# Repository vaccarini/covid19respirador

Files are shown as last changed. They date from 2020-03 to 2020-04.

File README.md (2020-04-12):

# COVID19 Respirador
Repositorio de un respirador mecánico basado en recomendaciones médicas.

## Introducción
En progreso. Véase el documento: https://docs.google.com/document/d/1z06rEOX_Jf6soLEfomvGs7rINXRS_1dPuQfoMjTGBHs/edit?usp=sharing

## Motivación
La mayoría de los respiradores open source, no cubren los requerimientos médicos mínimos que se necesitan para tratar a un paciente que necesitan tratamiento para el coronavirus.

El diseño de un respirador que funcione y que permita cubrir la baja disponibilidad de los ventiladores UCI se hace imperante. 

Este proyecto intenta crear un ventilador que funcione para los casos indicados.

## Diagrama
En progreso. Véase el documento: https://docs.google.com/document/d/1z06rEOX_Jf6soLEfomvGs7rINXRS_1dPuQfoMjTGBHs/edit?usp=sharing

## Software
El sistema utilizará un módulo arduino. Se buscan colaboradores para el desarrollo y otros aspectos asociados.

## Contacto
Para integrarse al proyecto por favor contactarse con Martín Vaccarini en martin.vaccarini@gmail.com.

## Colaboración en repositorio
* Abrir un nuevo Issue, Forkear el proyecto o realizar un Pull Request.
* También se necesita ayuda en el documento del proyecto: https://docs.google.com/document/d/1z06rEOX_Jf6soLEfomvGs7rINXRS_1dPuQfoMjTGBHs/edit?usp=sharing

Colaboradores:
* Martín Vaccarini (autor) (@vaccarini)
* Ignacio Tolosa (asesor repositorio) (@itolosa)
* Mateo Roldan (alumno escuela Técnica 5)
* Gaston Calderon (alumno escuela técnica 5)
* Eduardo Hisch fábrica de PCB´s
* Javier Schwindt (donó sensor MAF) 
* Adrian Merlo (interlocutor para recibir donaciones)
* Martin ( impresos 3D)
* Nicolas Dumic (colabora teniendo otro proyecto en caminando)
* Walter van Derdonckt (argentina)
* Jon Ander Oribe (España)
* Guille Clave (argentina)
* Sebastian Padilla (españa)

* (Por completar)

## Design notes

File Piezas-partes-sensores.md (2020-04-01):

# Piezas, Partes y Sensores

En esta sección se presentan algunas investigaciones realizadas con el propósito de explorar alternativas 
que permitan la obtención de piezas, sensores con disponibilidad y relativamente baratas.

# Sensores

## Sensores de flujo de aire

Dentro de las alternativas evaluadas como factibles se encuentran:
* Sensor de aspirometría de grado médico: SFM3000 (rango de 0 - 300 lpm)
* Tubo de venturi impreso en 3d usando un sensor de diferencial de presión como el MPX5010DP
* Sensor MAF (hot wire) con medición mínima de 50 kg/h (aprox 0.68 lpm)
* Sensores de ultrasonido
* Sensor de flujo usando aspas de ventilador y medir las revoluciones por efecto hall.

## Sensores de presión
Alternativas viables:
* Bmp280

## Piezas
* Arduino UNO
*LCD 4X18
*jostick arduino
*Placa potencia up arduino
*Sensor BMP280 (2)
*Solenoid caudal (3)
*Sensor caudalimetro (proycto MAF)
*Sensor caudalimetro (proyecto ultrasonido)
*Sensor caudalimetro (proyecto efecto hall)
*3d print (proyecto Humificador gases)
*Impresion 3D (proyecto Filtro Humdo)
*Imprsion 3d (proyecto Pipeta interconexion - paciente)
*Filtro Termico 80c

## Válvulas
Alternativas exploradas:
* Servovalvulas construidas usando un servo motor de alto torque sobre una válvula neumática manual
* Válvulas neumáticas solenoides

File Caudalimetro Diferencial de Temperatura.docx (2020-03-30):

Caudalimetro Diferencial de Temperatura

30 marzo 2020

Para el proyecto covid19_respirador se pone a prueba como caudalimetro, sensor MAF de la marca Ford modelo 93BB-I2B579-BA AFH60-02A, instalado en vehículo Mitsubishi Space Weather año 2009.-

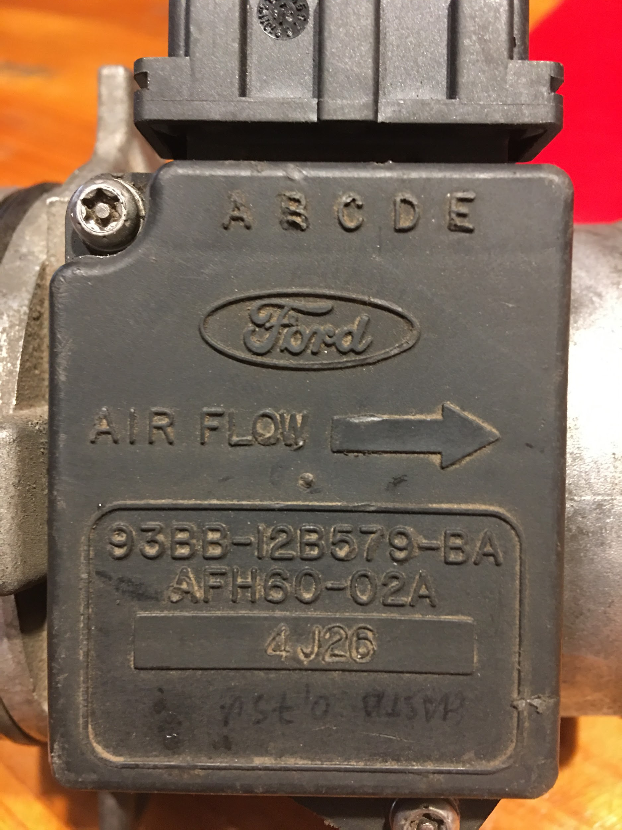
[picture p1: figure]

con 5 pines de conexión que paso a comentar como son

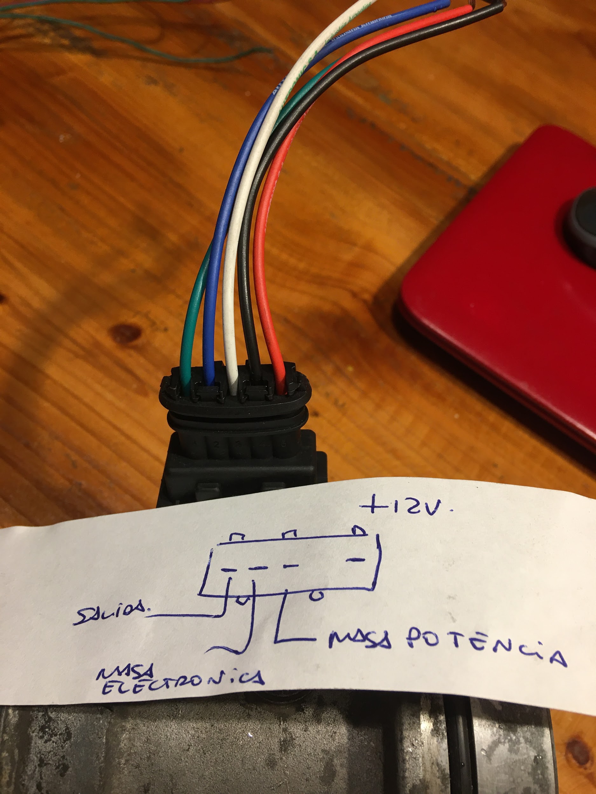
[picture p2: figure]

pin 1 rojo 12v

pin 2 negro no conectado

pin 3 blanco gnd bateria 12v

pin 4 azul gnd electrónica

pin 5 verde bus dato

de desmonta del cuerpo, porque para realizar las mediciones se colocara sobre tubo plástico de 50 mm de diámetro exterior

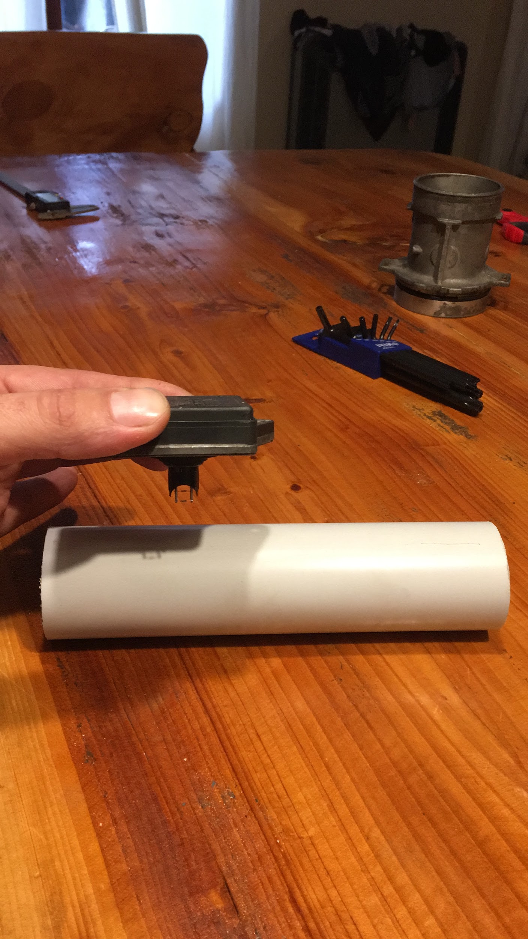
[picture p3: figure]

se fabrica nueva pieza de unión entre el caño y el sensor, se deja archivo IGS, para poder imprimir

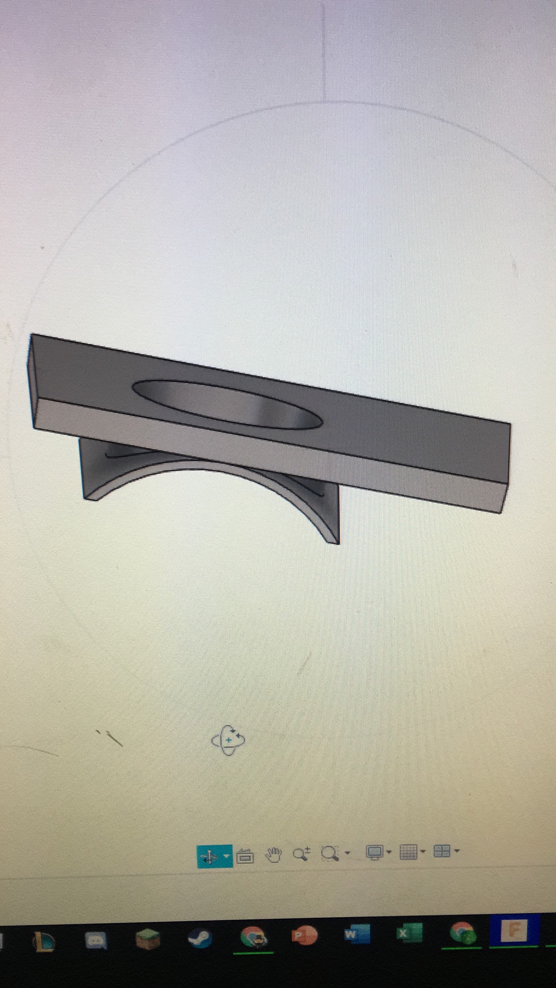
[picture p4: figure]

y se imprimen tapones para los extremos del caño, donde se podrá agujerear a medida para los racores de conexión de mangueras de aire.

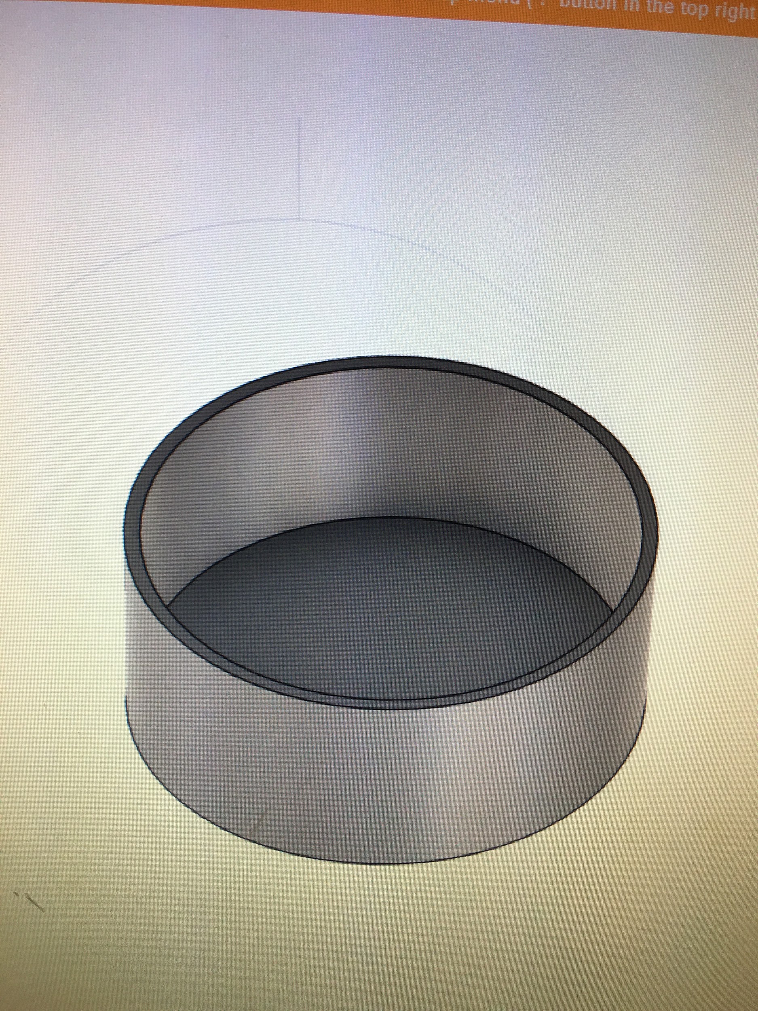
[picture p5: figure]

las mediciones iniciales, sobre el cuerpo original del MAF, nos da valores de 05 volt a 3 volt. por ese motivo se decide reducir la sección y conseguir mejor precisión del caudal a medir.

una vez que logremos medir el máximo de caudal, y que el MAF entregue los 5 vlt, de maxima medición, se debe colocar en el extremo del caño un anemómetro, con el fin de poder calcular la velocidad de la masa gaseosa que circula por el interior.

Utilizando las ecuaciones

tasa del flujo másico : M = dsA, donde M es la tasa de flujo másico, d es la densidad del fluido y s es la velocidad del fluido a través del área de la superficie A

tasa de flujo volumétrico: V = M/d donde V es la tasa de flujo volumétrico y M es la tasa de flujo másico

podemos sacar los cálculos de volumen que circulan dentro del caño.

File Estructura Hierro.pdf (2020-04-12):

ESTRUCTURA DE HIERRO

Bien llegamos al momento en que ya tenemos todo medio terminado y nos está haciendo falta colocarlo en algún habitáculo, lo normal hubiera sido algo como, pequeño, portátil y por sobre todo lindo. En nuestro caso lo hicimo a lo frankenstein, por que el tiempo apremiaba. así que nos pusimos a pensar como seria y que tendría. los dibujos fueron las primeras ideas, sin respetar las primeras palabras deseadas.

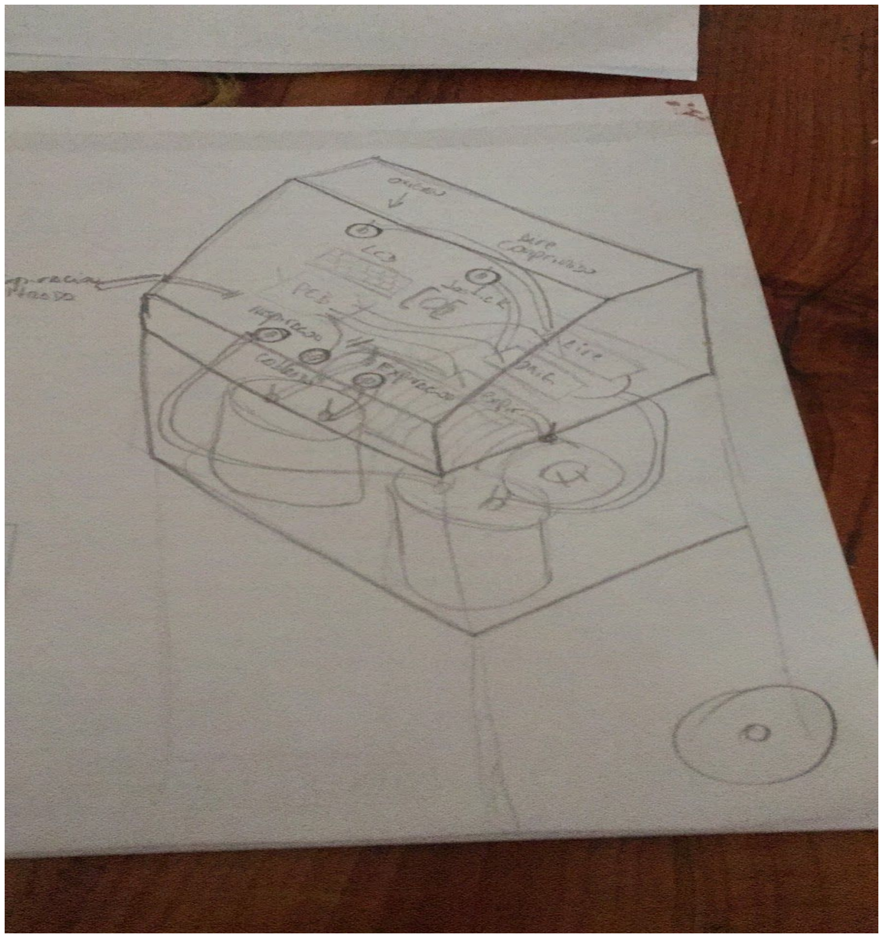
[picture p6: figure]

Menos mal que mi amigo Gaston Argañaraz, tiene mejor gusto y sabe trabajar el hierro, y no plasmó a mi franky con exactitud. Bueno la idea era que debía ser alto, más de lo que nos gustaría, pero tenía una lógica, es que las camas de los hospitales, ya de por si pasan los 80 Cm de alto, esto es por una cuestión de manejo del paciente, me debo imaginar, así que el equipo debía de quedar por encima de esa medida. Se armó la estructura de hierro, usando 10x10 mm y 10x20 mm, y realizamos tres divisiones, una tapa que contendría la parte electrónica de arduino y los comando para manejar el display. Una segunda etapa, también rebatible, que tendría la fuente de alimentación, los electro servos o solenoides, entradas de conexiones de 220V, y el sistema de encendido, ¡¡ si si , lo dejamos ahí dentro por que de esta manera evitamos que cualquier negligencia apague el equipo entero. Y por último dejamos la división que tendrá, el filtro térmico, el filtro de hipoclorito de sodio y el humidificador de aire. son los tres componentes que queríamos lejos de la instalación eléctrica, y de la electrónica. Aca les dejo la foto en donde queda ya terminado la estructura, y a futuro a cubrir a la zingueria

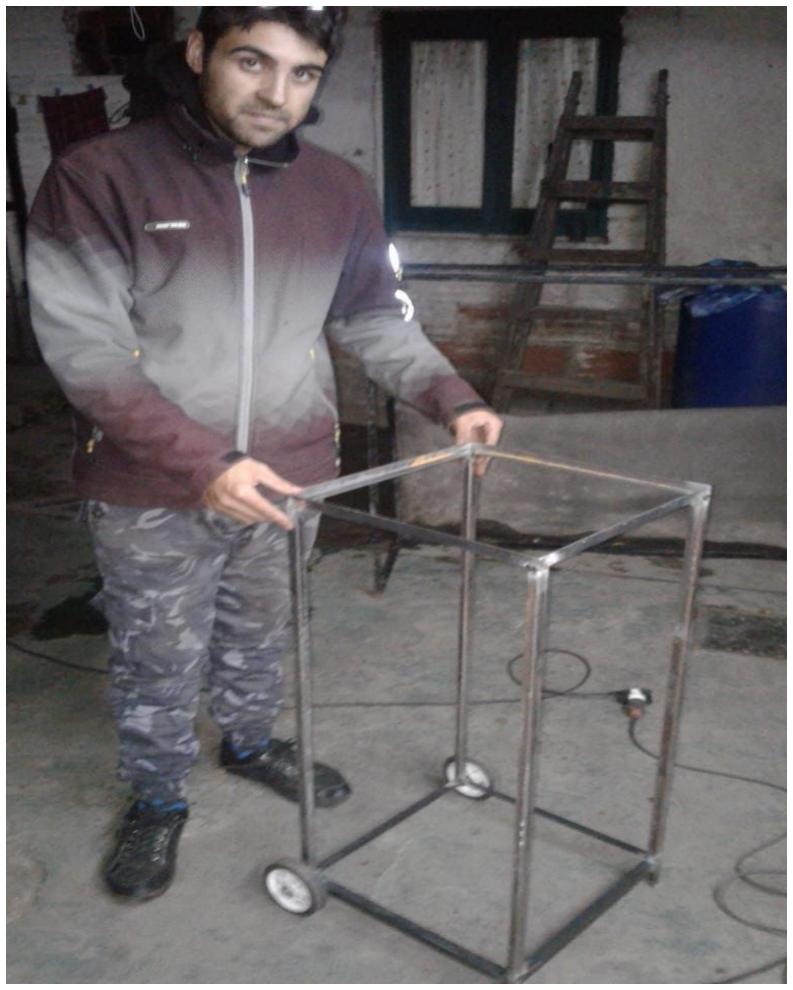
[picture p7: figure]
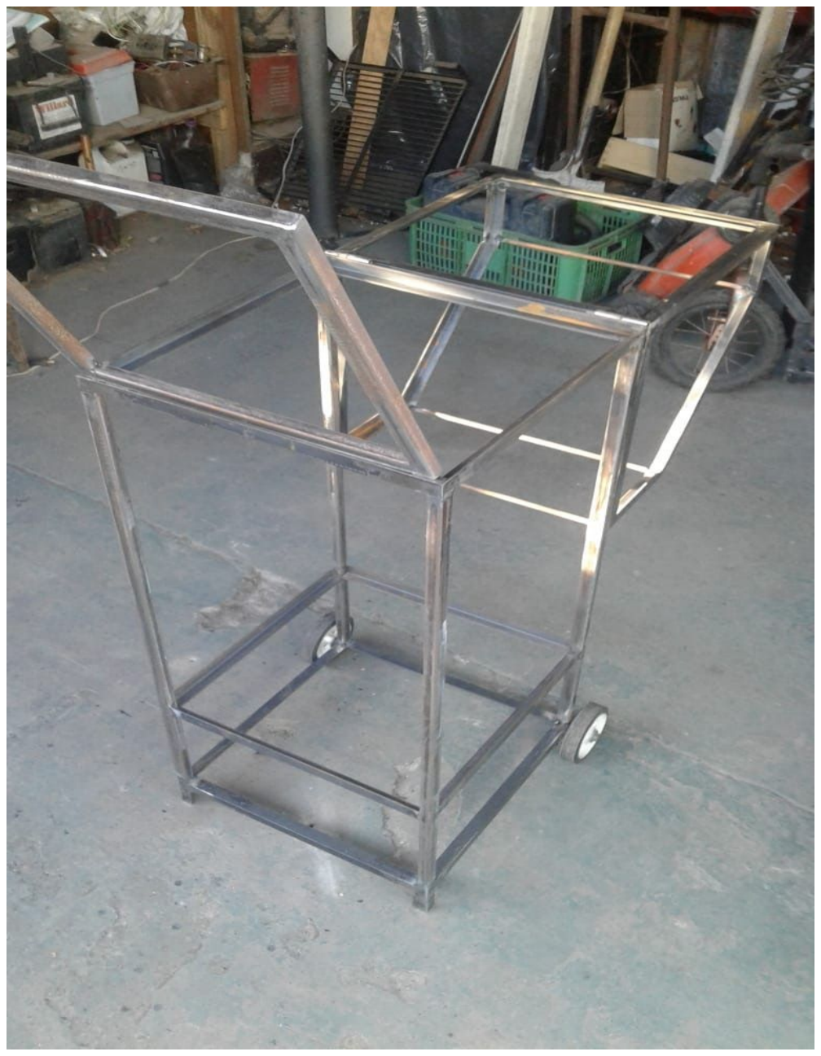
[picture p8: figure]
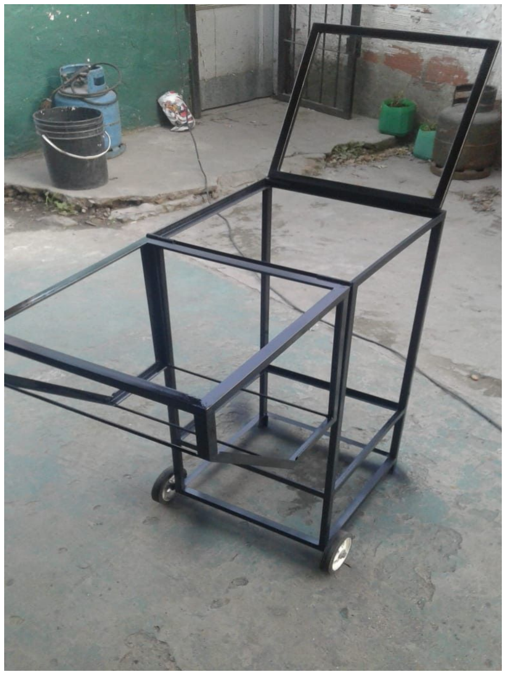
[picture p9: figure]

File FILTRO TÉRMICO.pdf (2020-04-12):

FILTRO TÉRMICO

En este apartado comentaré, lo diseñado hasta el momento como una de las soluciones posibles para poder realizar un filtro térmico, que con el fin de conseguir la disminución de la virulencia exhalada. Se ideó un dispositivo de fácil fabricación y con materiales al alcance de la mano, que ha sido la guía de este proyecto de respirador.
Los materiales que necesitaremos, son 3 Mts de caño de cobre de medida ¾” pulgada o en su defecto de ½” pulgada, en este caso pudimos conseguir la primer medida, por lo que realizaremos nuestro filtro, junto a boquillas de conexión para gas conocidas como HidroBronce, igualmente puede realizarse con cualquier boquilla que pueda ser conectada posteriormente a una rosca de ½” pulgada.

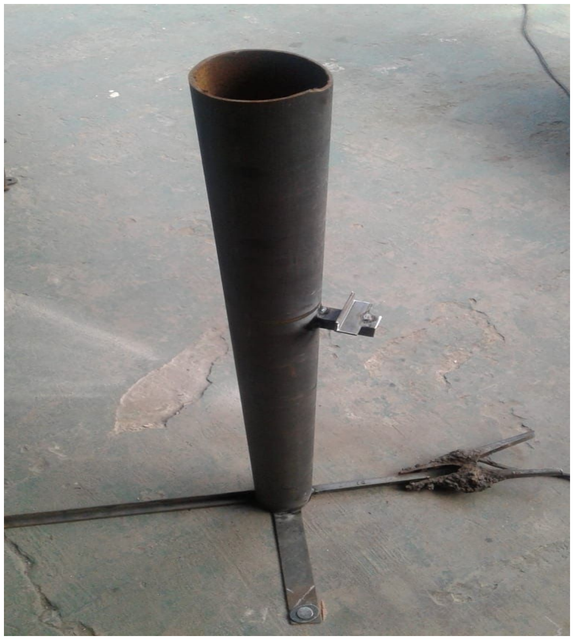
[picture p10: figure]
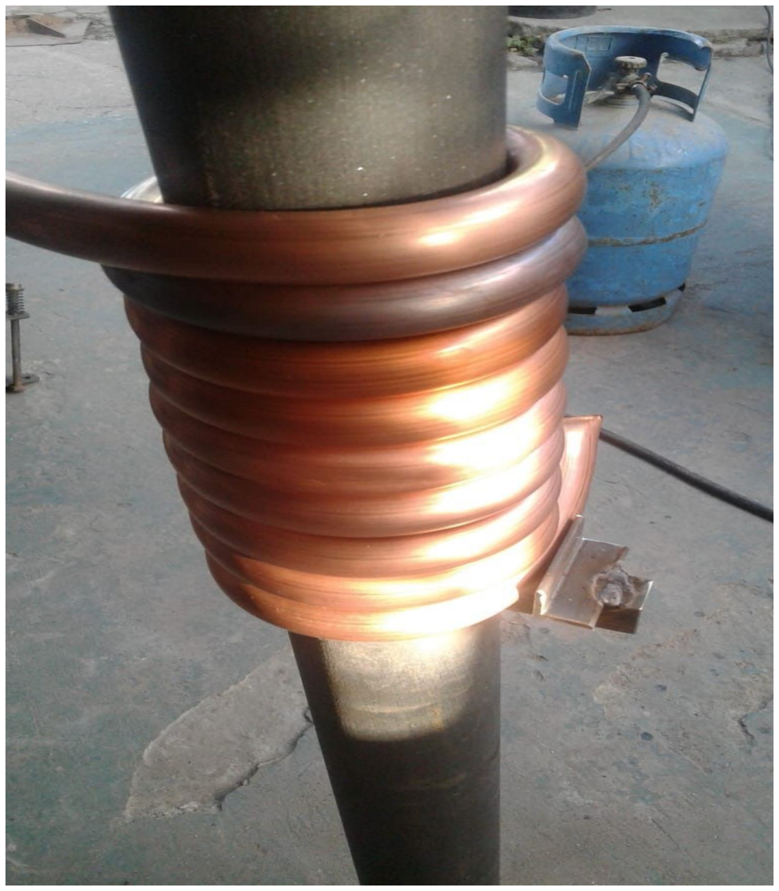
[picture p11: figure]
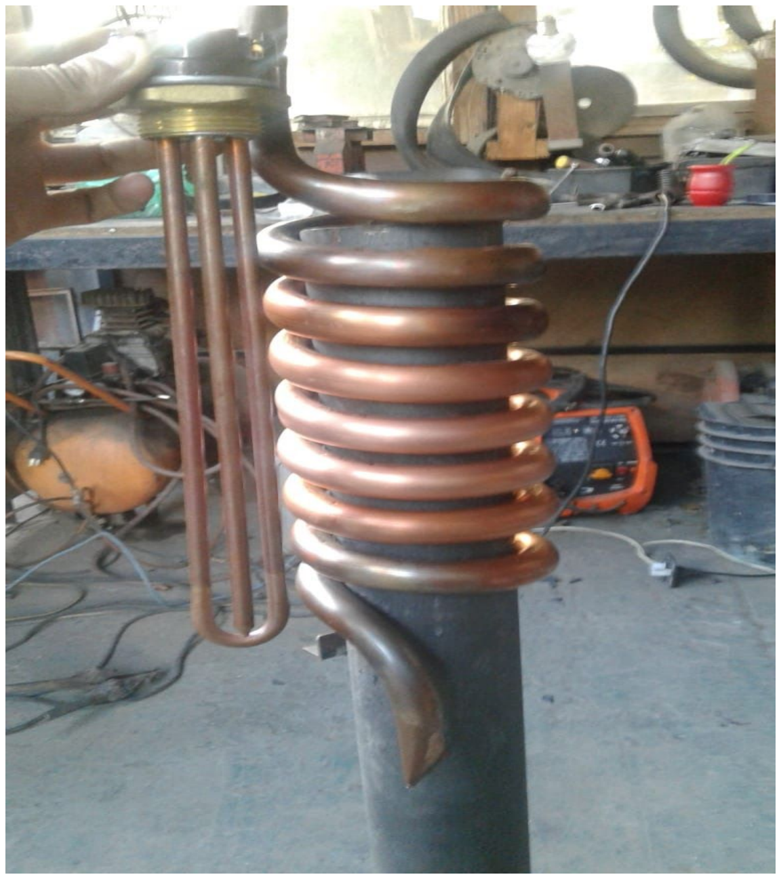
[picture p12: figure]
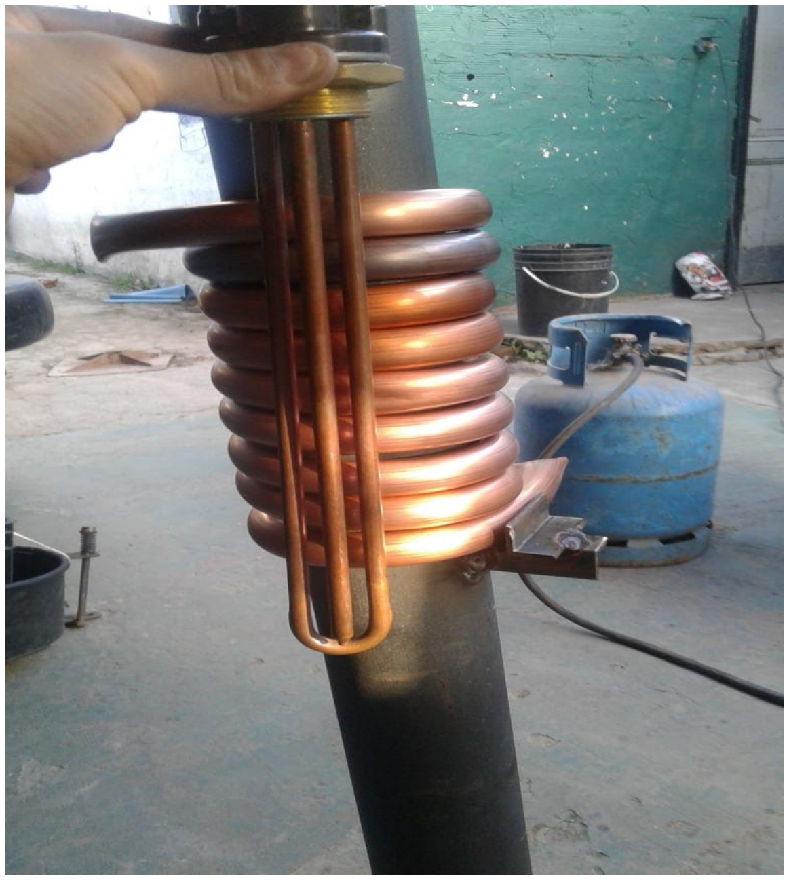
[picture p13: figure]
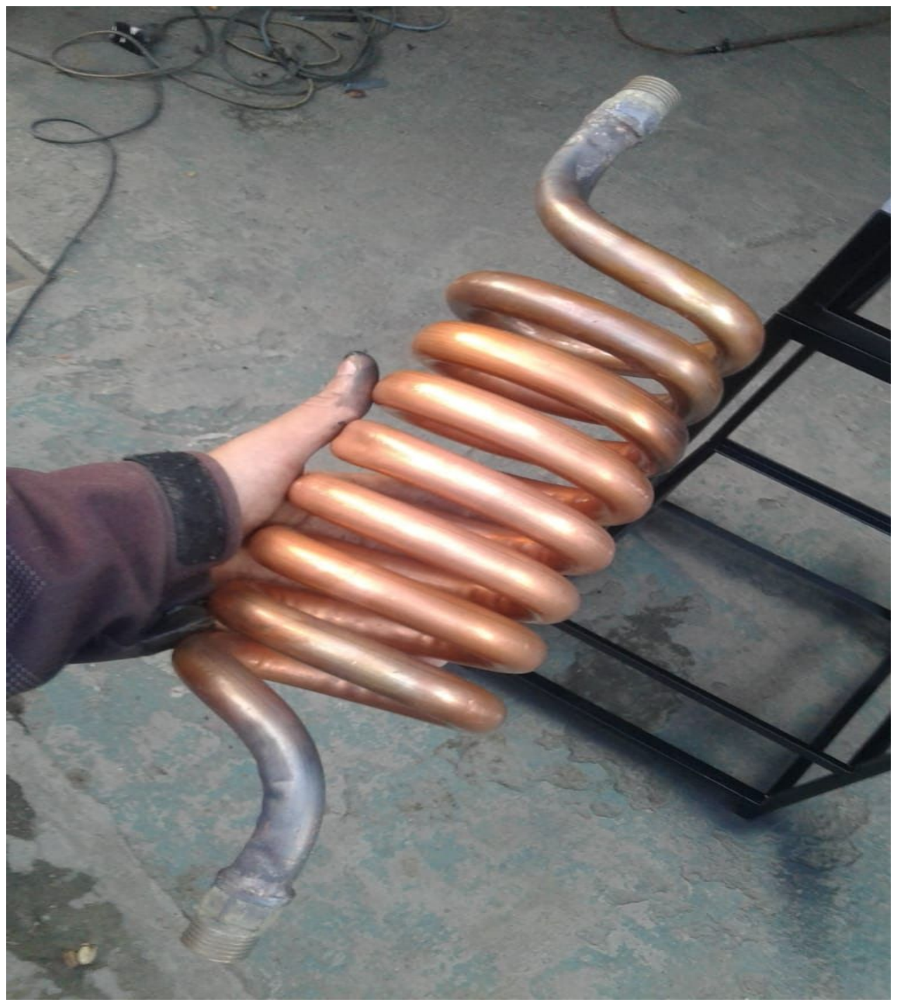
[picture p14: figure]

En las imágenes queda plasmado el proceso para doblar el caño, pero antes de esto el caño debe ser llenado con arena, y vibrado por al menos unos 15 minutos, logrando así que se apelmace bien la arena. Luego se fabricó una guia con un caño y dos planchuelas, por que la verdad que cuesta bastante trabajo poder doblarlo. Ya logrado el espiral que queríamos, calculamos el largo de la resistencia de calor y podemos estirar si lo deseamos, o en nuestro caso que nos quedamos cortos con solamente dos metros de caño, por eso al principio detallaba, que sería necesario al menos tres metros de esta cañería.
Bien ahora ya tenemos medio camino recorrido, así que solo queda soldar las conexiones, en nuestro caso rosca de ½” pulga, por que asi nos conviene a los conectores que conseguimos. Todo este sistema nos va mostrando de a poco la idea, ya que por dentro de este espiral se coloca la resistencia térmica que se ve en las fotos. Esta resistencia es de

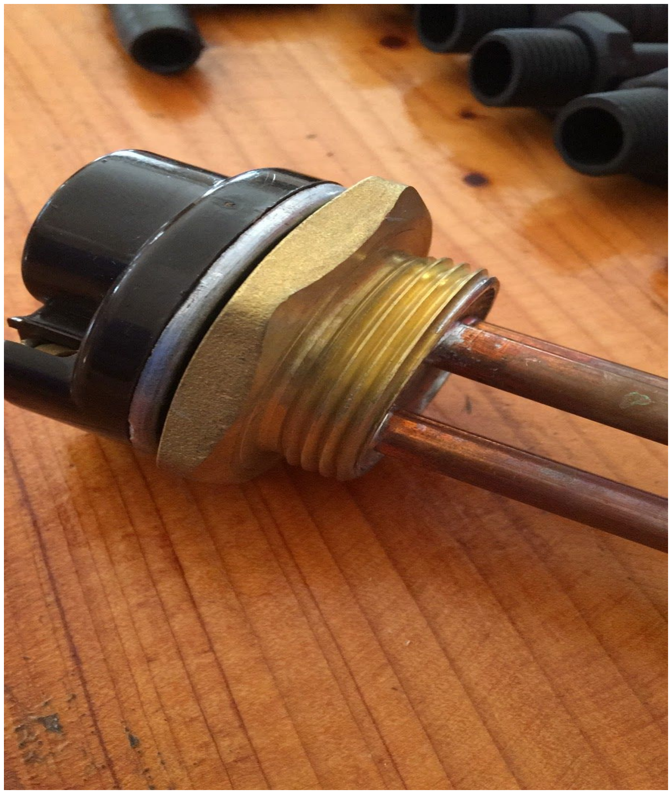
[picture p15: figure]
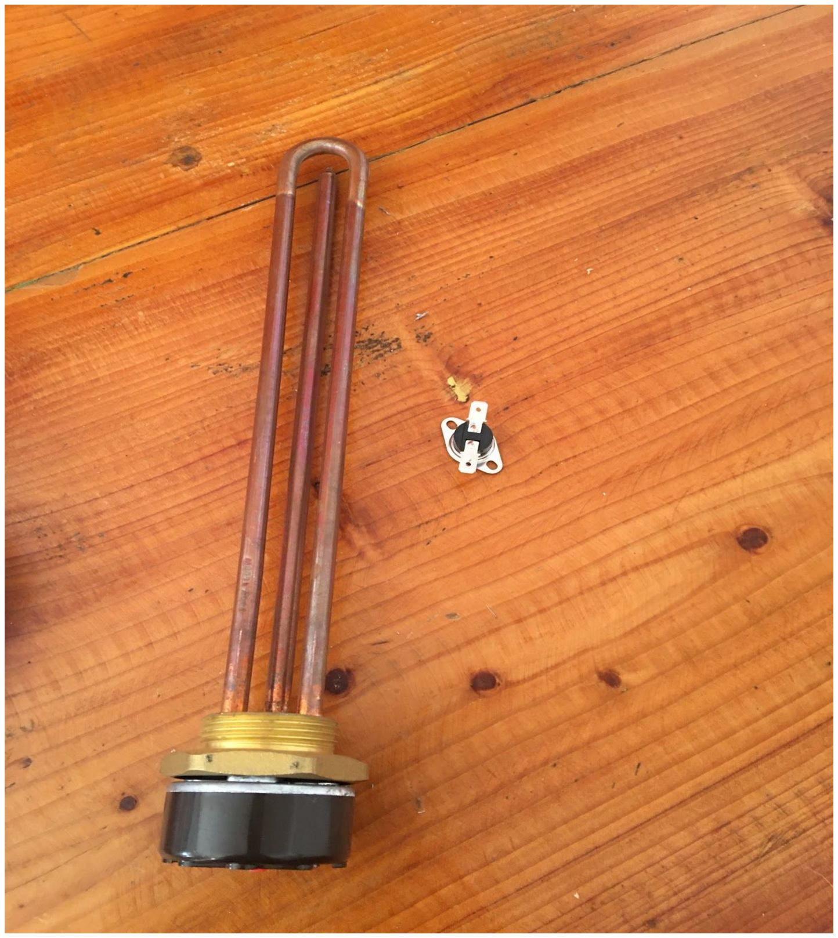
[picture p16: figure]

calefones eléctricos y son fáciles de conseguir.

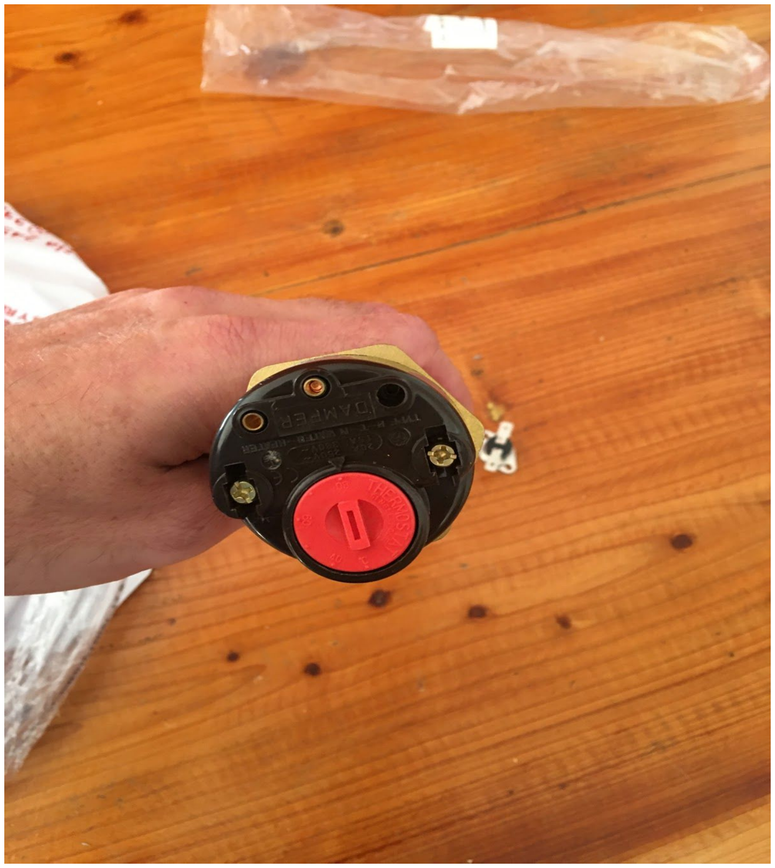
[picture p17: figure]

Bien en las imágenes van a ver que el cabezal negro, corresponde a la termocupla, que está regulada a 80 c grados, que es lo normal en los termotanques, y lo que ven al lado de la resistencia, de color gris es un termistor, que se colocara en el tubo que cubrirá todo, y que es de 100 c grados, y se instalará eléctricamente en serie con el propio de la resistencia, y ser, así un sistema de seguridad. El funcionamiento es que cortara siempre a los 80 C grados y en caso de falla, el termistor hará de salvavida y cortará el suministro eléctrico a los 100 C grados centígrados.-
Ya solo queda cubrir todo el proyecto con un tubo zincado y esto si lo mandamos a realizar a un zinguero, que es el artesano.-

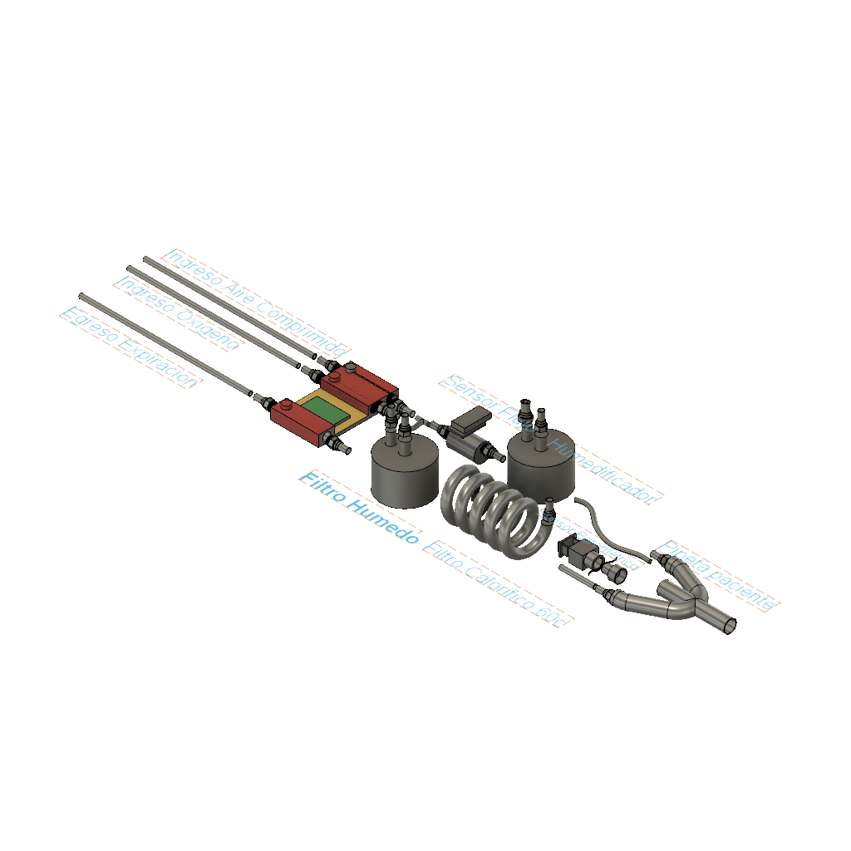
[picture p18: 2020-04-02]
covid19-respirador-base_V2 v1.png

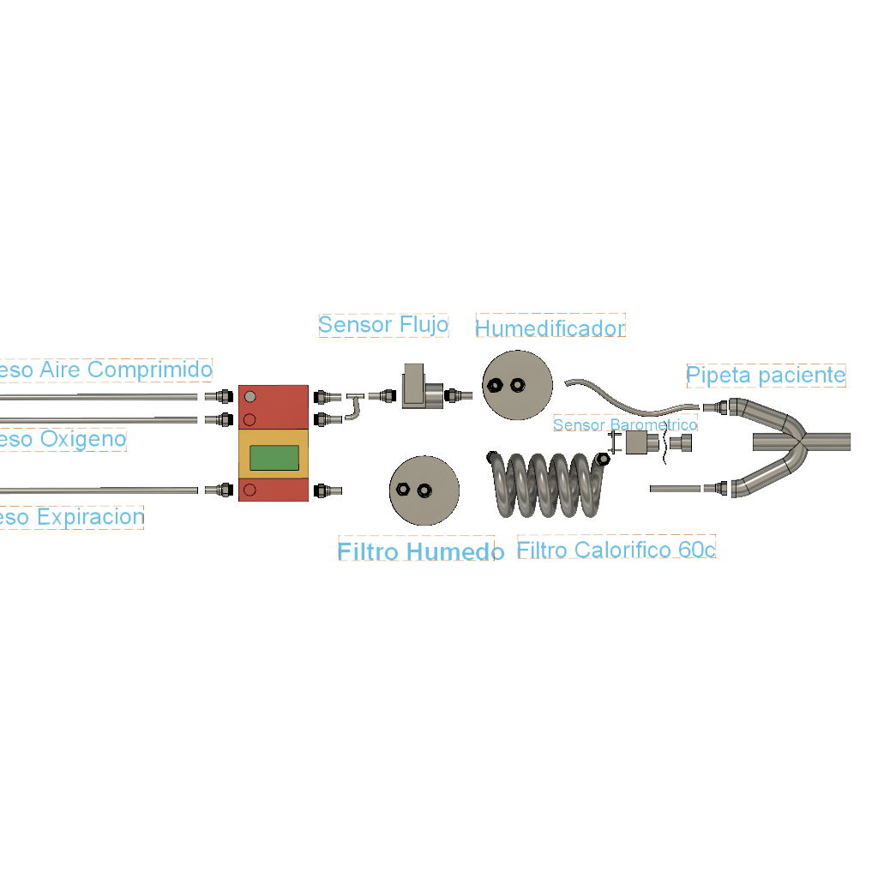
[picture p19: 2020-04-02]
covid19-respirador-base_V2 v1_F.png

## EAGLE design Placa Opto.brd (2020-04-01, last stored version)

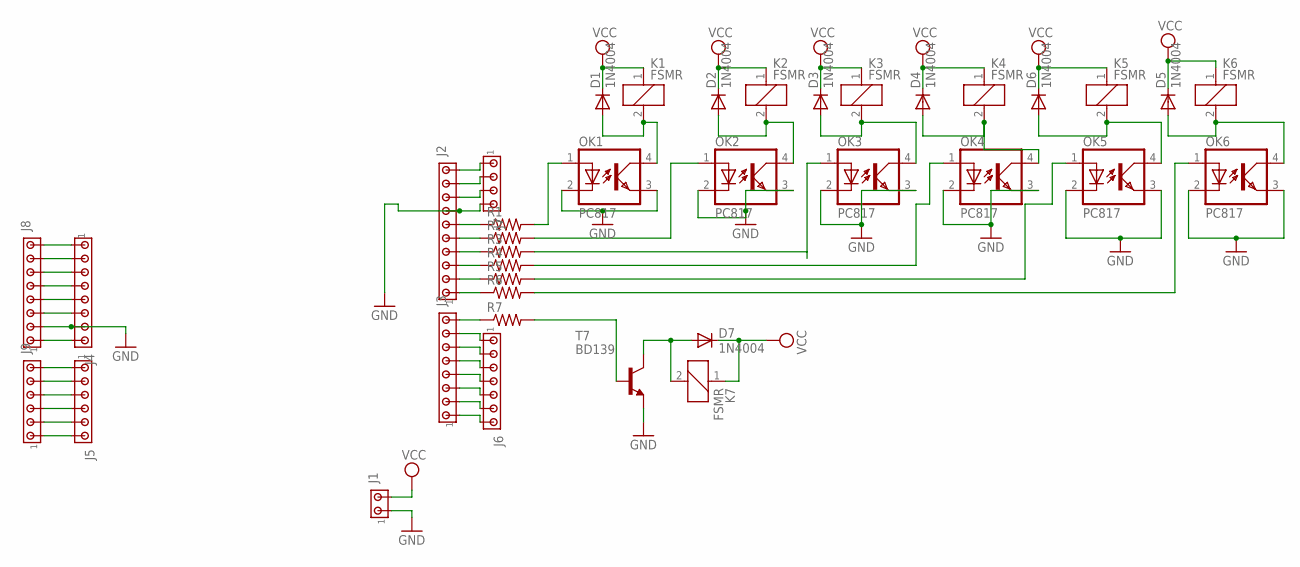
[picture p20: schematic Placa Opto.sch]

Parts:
D1, D2, D3, D4, D5, D6, D7: 1N4004; DO41-10
J1: MTA02-156; 1X2MTA
J2: MTA10-100; 10X10MTA
J3, J4, J8: MTA08-100; 10X08MTA
J5, J9: MTA06-100; 10X06MTA
J6: MTA07-100; 10X07MTA
J7: MTA04-100; 10X04MTA
K1, K2, K3, K4, K5, K6, K7: FSMR
OK1, OK2, OK3, OK4, OK5, OK6: PC817; DIL04
R1, R2, R3, R4, R5, R6, R7: R-US_0207/10; 0207/10
T7: BD139; TO126

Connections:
GND: J1.1, J2.7, J4.7, J7.4, J8.2, OK1.2 (C), OK1.3 (EMIT), OK2.2 (C), OK2.3 (EMIT), OK3.2 (C), OK3.3 (EMIT), OK4.2 (C), OK4.3 (EMIT), OK5.2 (C), OK5.3 (EMIT), OK6.2 (C), OK6.3 (EMIT), T7.1 (E)
unnamed: J2.1, R6.1
unnamed: J2.2, R5.1
unnamed: J2.3, R4.1
unnamed: J2.4, R3.1
unnamed: J2.5, R2.1
unnamed: J2.6, R1.1
unnamed: OK1.1 (A), R1.2
unnamed: D1.A, K1.2, OK1.4 (COL)
unnamed: OK2.1 (A), R2.2
unnamed: D2.A, K2.2, OK2.4 (COL)
unnamed: OK3.1 (A), R3.2
unnamed: D3.A, K3.2, OK3.4 (COL)
unnamed: OK4.1 (A), R4.2
unnamed: D4.A, K4.2, OK4.4 (COL)
unnamed: OK5.1 (A), R5.2
unnamed: OK6.1 (A), R6.2
unnamed: D5.A, K6.2, OK6.4 (COL)
unnamed: J3.8, R7.1
unnamed: R7.2, T7.3 (B)
unnamed: D7.A, K7.2, T7.2 (C)
unnamed: D6.A, K5.2, OK5.4 (COL)
unnamed: J3.7, J6.1
unnamed: J3.6, J6.2
unnamed: J3.5, J6.3
unnamed: J3.4, J6.4
unnamed: J3.3, J6.5
unnamed: J3.2, J6.6
unnamed: J3.1, J6.7
unnamed: J2.8, J7.3
unnamed: J2.9, J7.2
unnamed: J2.10, J7.1
unnamed: J4.1, J8.8
unnamed: J4.2, J8.7
unnamed: J4.3, J8.6
unnamed: J4.4, J8.5
unnamed: J4.5, J8.4
unnamed: J4.6, J8.3
unnamed: J4.8, J8.1
unnamed: J5.1, J9.6
unnamed: J5.2, J9.5
unnamed: J5.3, J9.4
unnamed: J5.4, J9.3
unnamed: J5.5, J9.2
unnamed: J5.6, J9.1
VCC: D1.C, D2.C, D3.C, D4.C, D5.C, D6.C, D7.C, J1.2, K1.1, K2.1, K3.1, K4.1, K5.1, K6.1, K7.1

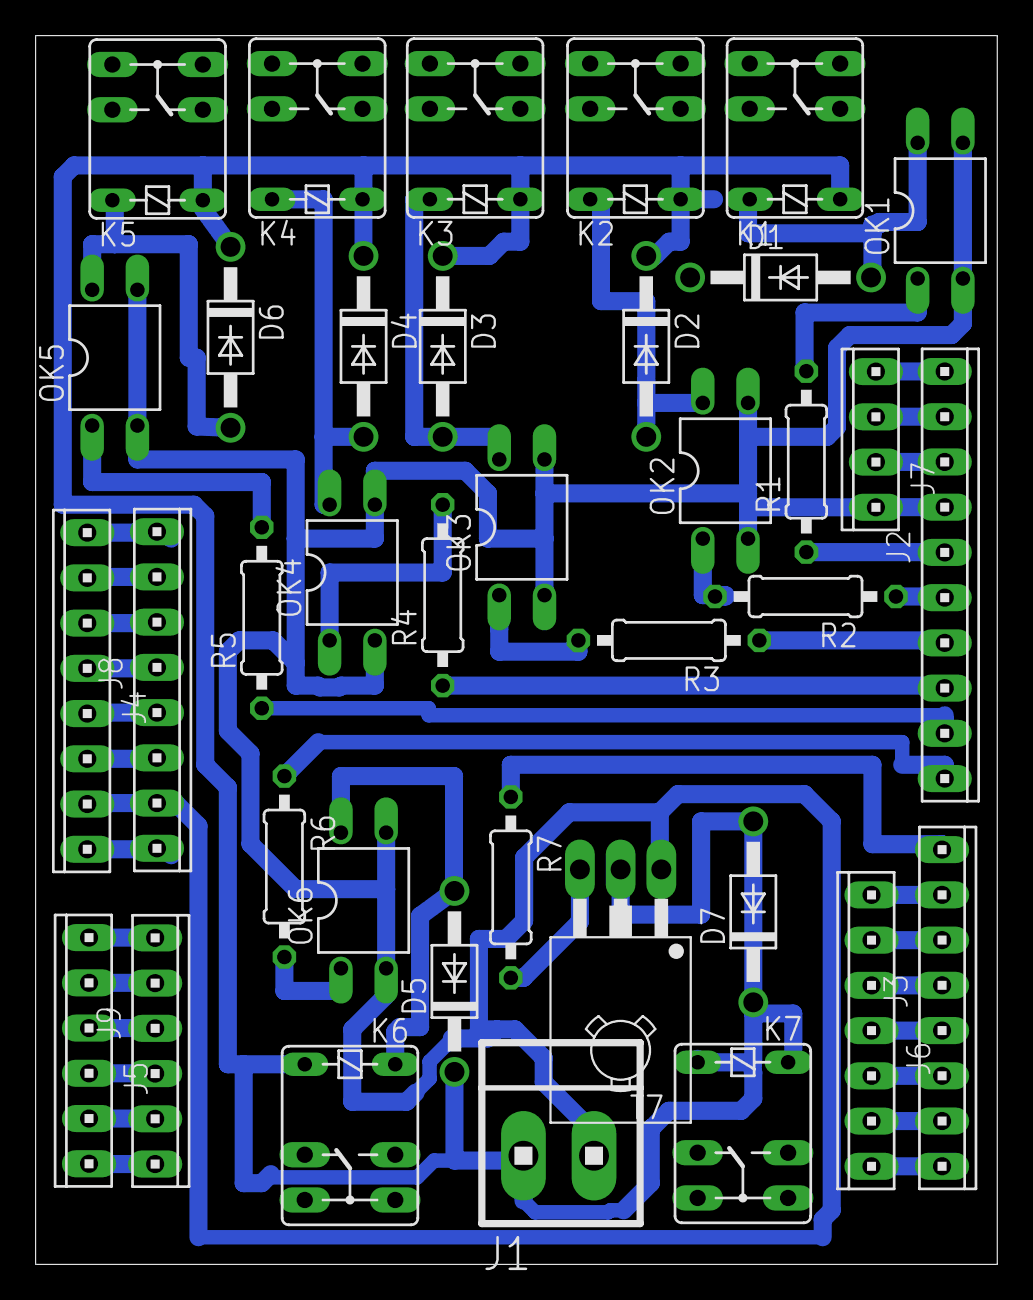
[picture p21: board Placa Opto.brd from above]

Board: 2 copper layers, 54.0 x 69.0 mm, 37 parts (0 on the bottom side), 46 nets.

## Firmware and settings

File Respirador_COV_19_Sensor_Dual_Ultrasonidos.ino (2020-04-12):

int Trig=12;
int Echo=13;

int Trig_2=7;
int Echo_2=8;

float sound_velocity=29.2;
int delay_for_writer=50;

void setup() {
  // put your setup code here, to run once:
  Serial.begin(9600);
  pinMode(Trig,OUTPUT);
  pinMode(Echo,INPUT);
  pinMode(Trig_2,OUTPUT);
  pinMode(Echo_2,INPUT);
}

void loop() {
  // put your main code here, to run repeatedly:
  float  duracion;
  float  duracion_2;
  float  distancia;
  float  distancia_2;

  digitalWrite(Trig,LOW);
  delayMicroseconds(4);
  digitalWrite(Trig,HIGH);
  delayMicroseconds(10);
  digitalWrite(Trig,LOW);
  
  duracion=pulseIn(Echo_2,HIGH);
  distancia= duracion/sound_velocity;

  Serial.print("From TRIGGER 1 to ECHO 2");
  Serial.print(distancia);
  delay(delay_for_writer);
  Serial.print('\n');

  digitalWrite(Trig_2,LOW);
  delayMicroseconds(4);
  digitalWrite(Trig_2,HIGH);
  delayMicroseconds(10);
  digitalWrite(Trig_2,LOW);
  
  duracion_2=pulseIn(Echo,HIGH);
  distancia_2= duracion_2/sound_velocity;

   Serial.print("From TRIGGER 2 to ECHO 1");
   Serial.print(distancia_2);
   delay(delay_for_writer);
   Serial.print('\n');

}

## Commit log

2020-03-28 esquema respirador
    Esquema de respirador por inserción equipos de presión de aire y oxigeno
2020-03-30 Add files via upload
    Sensor volumetrico Diferencial Termico, mediante MDF vehiculo
2020-04-01 Placa PCB de arduino a placa encastre - comando etapa de potencia
    Por colaborativo de Gaston Calderon, quien diseño PC, para poder comandar las etapas de Solenoides (3), resistencias calorificas (1), pines libres arduino para Buzzer (1), Sensores barometricos (2), display LCD 4x18, Comando jostick arduino (1).-
    [Placa Opto.brd, Placa Opto.sch, Placa Tran.brd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]
2020-04-02 Create PCB´s
    Archivos Download PCB EAGLE
2020-04-02 Create PCB
2020-04-11 Create Respirador_COV_19_Sensor_Dual_Ultrasonidos.ino
    Script for the dual ultrasonic sensor
2020-04-12 Filtro Termico
    Se detalla la idea y lo que se fabrico
2020-04-12 Estructura de hierro
    Se comenta la idea y su fabricacion
